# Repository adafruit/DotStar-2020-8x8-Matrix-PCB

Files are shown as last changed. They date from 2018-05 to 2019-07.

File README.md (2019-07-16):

## Adafruit DotStar High Density 8x8 Grid - 64 RGB LED Pixel Matrix PCB

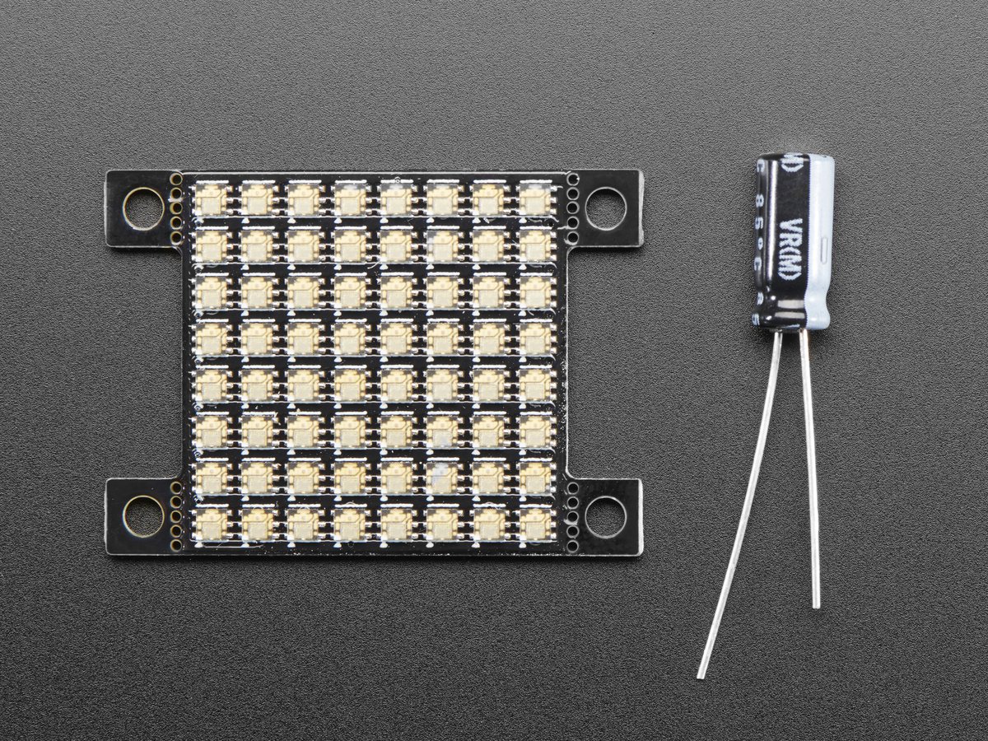
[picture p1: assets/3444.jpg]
<a href="http://www.adafruit.com/products/3444"><br/>
Click here to purchase one from the Adafruit shop</a>

PCB files for the Adafruit DotStar High Density 8x8 Grid - 64 RGB LED Pixel Matrix. Format is EagleCAD schematic and board layout
* https://www.adafruit.com/product/3444

### Description

Do not eat this LED grid just because it is so colorful and bite-sized! This is the tiniest little LED grid we could make, with 64 full RGB color pixels in a square that is only 1" by 1" square (thats 25.4mm x 25.4mm for you metric-lovers). Best of all, these are little DotStar LEDs, with built in PWM drivers, so you only need two digital I/O pins to get a-glowin'.

But do not be fooled by their small size, each LED is still incredibly, blindingly bright just like the DotStars/NeoPixels you know and love. These are the same integrated LEDs that are used in [our new fancy DotStar strips](https://www.adafruit.com/categories/885) just really small.

Arranged in an 8x8 matrix, each pixel is individually addressable: like NeoPixels, DotStar LEDs have an embedded microcontroller **inside the LED**. You can set the color/brightness of each LED to 24-bit color (8 bits each red green and blue). Each LED acts like a shift register, reading incoming color data on the input pins, and then shifting the previous color data out on the output pin. By sending a long string of data, you can control an 'infinite' number of LEDs. The PWM is built into each LED-chip so once you set the color you can stop talking to the disk and it will continue to PWM all the LEDs for you.

Wiring it up is easy: there are two 4-pad connection ports on the back. Solder wires to the input port (+5V GND ClockIn and DataIn) and provide 5VDC to the +5V and ground pins, then connect the CIN/DIN pin to your microcontroller. If you have hardware SPI, use the SCK and MOSI pins respectively. You'll also need to make a common ground from the 5V power supply to the microcontroller/Arduino. Since each LED can draw as much as 40mA (thats up to 2.5 Amps per panel if all LEDs are on bright white!) we suggest our 5V 2A power supply if you're going to use full brightness and a lot of white. For most uses, you'll see about 0.5A of current per panel, and you can set the brightness to drop that down. Note that so much current through a small board can make it toasty!

To keep the board small, we did not put any small surface-mount capacitors on the front. Instead, there's a power/ground pad set on the back and a 220uF capacitor that you can solder onto the back for a compact fit. There's also four mounting holes that you can use for attachment, or snap them off with pliers if you want a perfect 1" square.

[Check out our tutorial showing wiring, power usage calculations, example code for usage, etc!](https://learn.adafruit.com/adafruit-dotstar-leds)

### License

Adafruit invests time and resources providing this open source design, please support Adafruit and open-source hardware by purchasing products from [Adafruit](https://www.adafruit.com)!

Designed by Limor Fried/Ladyada for Adafruit Industries.

Creative Commons Attribution/Share-Alike, all text above must be included in any redistribution. See license.txt for additional details.

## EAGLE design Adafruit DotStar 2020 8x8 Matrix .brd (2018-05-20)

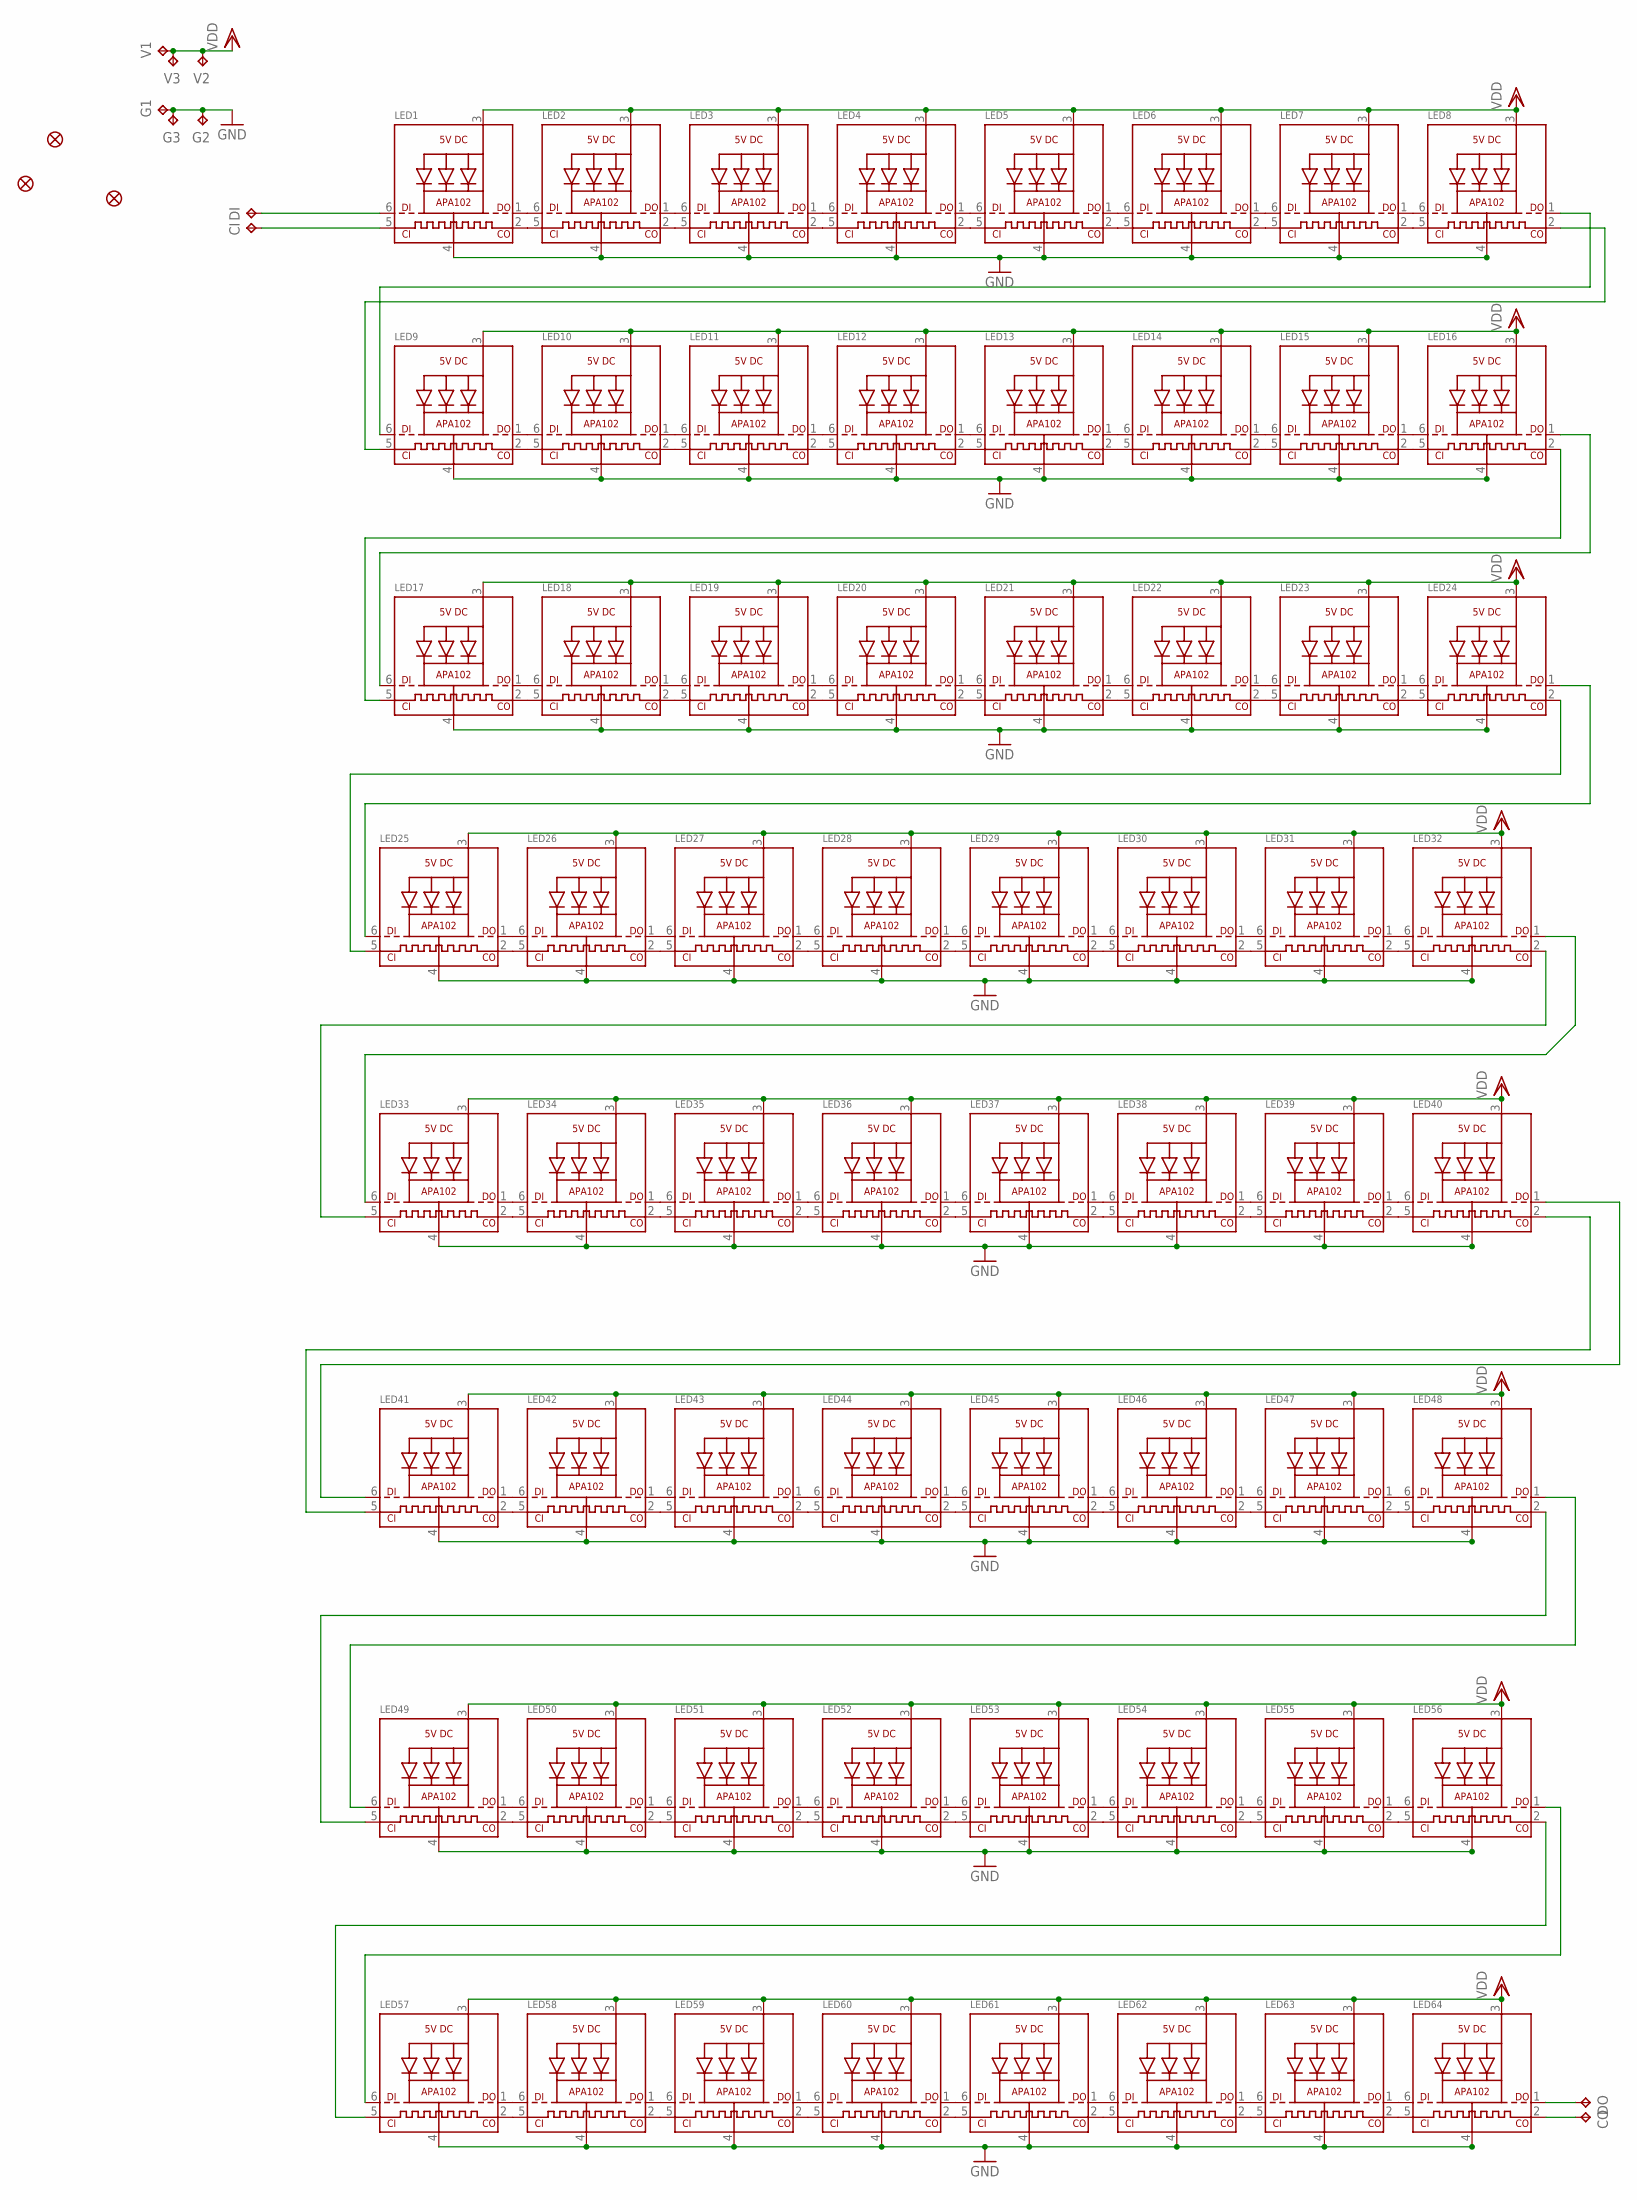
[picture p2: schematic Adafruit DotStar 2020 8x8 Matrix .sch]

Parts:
CI: TPTP20R; TP20R
CO: TPTP20R; TP20R
DI: TPTP20R; TP20R
DO: TPTP20R; TP20R
FID1, FID2, FID3: FIDUCIAL_0.5MM
G1, G2, G3: TPTP20R; TP20R
LED1, LED2, LED3, LED4, LED5, LED6, LED7, LED8, LED9, LED10, LED11, LED12, LED13, LED14, LED15, LED16, LED17, LED18, LED19, LED20, LED21, LED22, LED23, LED24, LED25, LED26, LED27, LED28, LED29, LED30, LED31, LED32, LED33, LED34, LED35, LED36, LED37, LED38, LED39, LED40, LED41, LED42, LED43, LED44, LED45, LED46, LED47, LED48, LED49, LED50, LED51, LED52, LED53, LED54, LED55, LED56, LED57, LED58, LED59, LED60, LED61, LED62, LED63, LED64: APA1022020; APA102_2020
V1, V2, V3: TPTP20R; TP20R

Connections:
C0: CO.TP, LED64.2 (CKO)
CIN: CI.TP, LED1.5 (CKI)
D0: DO.TP, LED64.1 (DO)
DIN: DI.TP, LED1.6 (DI)
GND: G1.TP, G2.TP, G3.TP, LED1.4 (GND), LED2.4 (GND), LED3.4 (GND), LED4.4 (GND), LED5.4 (GND), LED6.4 (GND), LED7.4 (GND), LED8.4 (GND), LED9.4 (GND), LED10.4 (GND), LED11.4 (GND), LED12.4 (GND), LED13.4 (GND), LED14.4 (GND), LED15.4 (GND), LED16.4 (GND), LED17.4 (GND), LED18.4 (GND), LED19.4 (GND), LED20.4 (GND), LED21.4 (GND), LED22.4 (GND), LED23.4 (GND), LED24.4 (GND), LED25.4 (GND), LED26.4 (GND), LED27.4 (GND), LED28.4 (GND), LED29.4 (GND), LED30.4 (GND), LED31.4 (GND), LED32.4 (GND), LED33.4 (GND), LED34.4 (GND), LED35.4 (GND), LED36.4 (GND), LED37.4 (GND), LED38.4 (GND), LED39.4 (GND), LED40.4 (GND), LED41.4 (GND), LED42.4 (GND), LED43.4 (GND), LED44.4 (GND), LED45.4 (GND), LED46.4 (GND), LED47.4 (GND), LED48.4 (GND), LED49.4 (GND), LED50.4 (GND), LED51.4 (GND), LED52.4 (GND), LED53.4 (GND), LED54.4 (GND), LED55.4 (GND), LED56.4 (GND), LED57.4 (GND), LED58.4 (GND), LED59.4 (GND), LED60.4 (GND), LED61.4 (GND), LED62.4 (GND), LED63.4 (GND), LED64.4 (GND)
unnamed: LED1.1 (DO), LED2.6 (DI)
unnamed: LED1.2 (CKO), LED2.5 (CKI)
unnamed: LED2.1 (DO), LED3.6 (DI)
unnamed: LED2.2 (CKO), LED3.5 (CKI)
unnamed: LED3.1 (DO), LED4.6 (DI)
unnamed: LED3.2 (CKO), LED4.5 (CKI)
unnamed: LED4.1 (DO), LED5.6 (DI)
unnamed: LED4.2 (CKO), LED5.5 (CKI)
unnamed: LED5.1 (DO), LED6.6 (DI)
unnamed: LED5.2 (CKO), LED6.5 (CKI)
unnamed: LED6.1 (DO), LED7.6 (DI)
unnamed: LED6.2 (CKO), LED7.5 (CKI)
unnamed: LED7.1 (DO), LED8.6 (DI)
unnamed: LED7.2 (CKO), LED8.5 (CKI)
unnamed: LED9.1 (DO), LED10.6 (DI)
unnamed: LED9.2 (CKO), LED10.5 (CKI)
unnamed: LED10.1 (DO), LED11.6 (DI)
unnamed: LED10.2 (CKO), LED11.5 (CKI)
unnamed: LED11.1 (DO), LED12.6 (DI)
unnamed: LED11.2 (CKO), LED12.5 (CKI)
unnamed: LED12.1 (DO), LED13.6 (DI)
unnamed: LED12.2 (CKO), LED13.5 (CKI)
unnamed: LED13.1 (DO), LED14.6 (DI)
unnamed: LED13.2 (CKO), LED14.5 (CKI)
unnamed: LED14.1 (DO), LED15.6 (DI)
unnamed: LED14.2 (CKO), LED15.5 (CKI)
unnamed: LED15.1 (DO), LED16.6 (DI)
unnamed: LED15.2 (CKO), LED16.5 (CKI)
unnamed: LED17.1 (DO), LED18.6 (DI)
unnamed: LED17.2 (CKO), LED18.5 (CKI)
unnamed: LED18.1 (DO), LED19.6 (DI)
unnamed: LED18.2 (CKO), LED19.5 (CKI)
unnamed: LED19.1 (DO), LED20.6 (DI)
unnamed: LED19.2 (CKO), LED20.5 (CKI)
unnamed: LED20.1 (DO), LED21.6 (DI)
unnamed: LED20.2 (CKO), LED21.5 (CKI)
unnamed: LED21.1 (DO), LED22.6 (DI)
unnamed: LED21.2 (CKO), LED22.5 (CKI)
unnamed: LED22.1 (DO), LED23.6 (DI)
unnamed: LED22.2 (CKO), LED23.5 (CKI)
unnamed: LED23.1 (DO), LED24.6 (DI)
unnamed: LED23.2 (CKO), LED24.5 (CKI)
unnamed: LED25.1 (DO), LED26.6 (DI)
unnamed: LED25.2 (CKO), LED26.5 (CKI)
unnamed: LED26.1 (DO), LED27.6 (DI)
unnamed: LED26.2 (CKO), LED27.5 (CKI)
unnamed: LED27.1 (DO), LED28.6 (DI)
unnamed: LED27.2 (CKO), LED28.5 (CKI)
unnamed: LED28.1 (DO), LED29.6 (DI)
unnamed: LED28.2 (CKO), LED29.5 (CKI)
unnamed: LED29.1 (DO), LED30.6 (DI)
unnamed: LED29.2 (CKO), LED30.5 (CKI)
unnamed: LED30.1 (DO), LED31.6 (DI)
unnamed: LED30.2 (CKO), LED31.5 (CKI)
unnamed: LED31.1 (DO), LED32.6 (DI)
unnamed: LED31.2 (CKO), LED32.5 (CKI)
unnamed: LED33.1 (DO), LED34.6 (DI)
unnamed: LED33.2 (CKO), LED34.5 (CKI)
unnamed: LED34.1 (DO), LED35.6 (DI)
unnamed: LED34.2 (CKO), LED35.5 (CKI)
unnamed: LED35.1 (DO), LED36.6 (DI)
unnamed: LED35.2 (CKO), LED36.5 (CKI)
unnamed: LED36.1 (DO), LED37.6 (DI)
unnamed: LED36.2 (CKO), LED37.5 (CKI)
unnamed: LED37.1 (DO), LED38.6 (DI)
unnamed: LED37.2 (CKO), LED38.5 (CKI)
unnamed: LED38.1 (DO), LED39.6 (DI)
unnamed: LED38.2 (CKO), LED39.5 (CKI)
unnamed: LED39.1 (DO), LED40.6 (DI)
unnamed: LED39.2 (CKO), LED40.5 (CKI)
unnamed: LED41.1 (DO), LED42.6 (DI)
unnamed: LED41.2 (CKO), LED42.5 (CKI)
unnamed: LED42.1 (DO), LED43.6 (DI)
unnamed: LED42.2 (CKO), LED43.5 (CKI)
unnamed: LED43.1 (DO), LED44.6 (DI)
unnamed: LED43.2 (CKO), LED44.5 (CKI)
unnamed: LED44.1 (DO), LED45.6 (DI)
unnamed: LED44.2 (CKO), LED45.5 (CKI)
unnamed: LED45.1 (DO), LED46.6 (DI)
unnamed: LED45.2 (CKO), LED46.5 (CKI)
unnamed: LED46.1 (DO), LED47.6 (DI)
unnamed: LED46.2 (CKO), LED47.5 (CKI)
unnamed: LED47.1 (DO), LED48.6 (DI)
unnamed: LED47.2 (CKO), LED48.5 (CKI)
unnamed: LED49.1 (DO), LED50.6 (DI)
unnamed: LED49.2 (CKO), LED50.5 (CKI)
unnamed: LED50.1 (DO), LED51.6 (DI)
unnamed: LED50.2 (CKO), LED51.5 (CKI)
unnamed: LED51.1 (DO), LED52.6 (DI)
unnamed: LED51.2 (CKO), LED52.5 (CKI)
unnamed: LED52.1 (DO), LED53.6 (DI)
unnamed: LED52.2 (CKO), LED53.5 (CKI)
unnamed: LED53.1 (DO), LED54.6 (DI)
unnamed: LED53.2 (CKO), LED54.5 (CKI)
unnamed: LED54.1 (DO), LED55.6 (DI)
unnamed: LED54.2 (CKO), LED55.5 (CKI)
unnamed: LED55.1 (DO), LED56.6 (DI)
unnamed: LED55.2 (CKO), LED56.5 (CKI)
unnamed: LED57.1 (DO), LED58.6 (DI)
unnamed: LED57.2 (CKO), LED58.5 (CKI)
unnamed: LED58.1 (DO), LED59.6 (DI)
unnamed: LED58.2 (CKO), LED59.5 (CKI)
unnamed: LED59.1 (DO), LED60.6 (DI)
unnamed: LED59.2 (CKO), LED60.5 (CKI)
unnamed: LED60.1 (DO), LED61.6 (DI)
unnamed: LED60.2 (CKO), LED61.5 (CKI)
unnamed: LED61.1 (DO), LED62.6 (DI)
unnamed: LED61.2 (CKO), LED62.5 (CKI)
unnamed: LED62.1 (DO), LED63.6 (DI)
unnamed: LED62.2 (CKO), LED63.5 (CKI)
unnamed: LED63.1 (DO), LED64.6 (DI)
unnamed: LED63.2 (CKO), LED64.5 (CKI)
unnamed: LED8.1 (DO), LED9.6 (DI)
unnamed: LED8.2 (CKO), LED9.5 (CKI)
unnamed: LED16.1 (DO), LED17.6 (DI)
unnamed: LED16.2 (CKO), LED17.5 (CKI)
unnamed: LED24.1 (DO), LED25.6 (DI)
unnamed: LED24.2 (CKO), LED25.5 (CKI)
unnamed: LED32.1 (DO), LED33.6 (DI)
unnamed: LED32.2 (CKO), LED33.5 (CKI)
unnamed: LED56.1 (DO), LED57.6 (DI)
unnamed: LED56.2 (CKO), LED57.5 (CKI)
unnamed: LED48.2 (CKO), LED49.5 (CKI)
unnamed: LED48.1 (DO), LED49.6 (DI)
unnamed: LED40.2 (CKO), LED41.5 (CKI)
unnamed: LED40.1 (DO), LED41.6 (DI)
VDD: LED1.3 (VDD), LED2.3 (VDD), LED3.3 (VDD), LED4.3 (VDD), LED5.3 (VDD), LED6.3 (VDD), LED7.3 (VDD), LED8.3 (VDD), LED9.3 (VDD), LED10.3 (VDD), LED11.3 (VDD), LED12.3 (VDD), LED13.3 (VDD), LED14.3 (VDD), LED15.3 (VDD), LED16.3 (VDD), LED17.3 (VDD), LED18.3 (VDD), LED19.3 (VDD), LED20.3 (VDD), LED21.3 (VDD), LED22.3 (VDD), LED23.3 (VDD), LED24.3 (VDD), LED25.3 (VDD), LED26.3 (VDD), LED27.3 (VDD), LED28.3 (VDD), LED29.3 (VDD), LED30.3 (VDD), LED31.3 (VDD), LED32.3 (VDD), LED33.3 (VDD), LED34.3 (VDD), LED35.3 (VDD), LED36.3 (VDD), LED37.3 (VDD), LED38.3 (VDD), LED39.3 (VDD), LED40.3 (VDD), LED41.3 (VDD), LED42.3 (VDD), LED43.3 (VDD), LED44.3 (VDD), LED45.3 (VDD), LED46.3 (VDD), LED47.3 (VDD), LED48.3 (VDD), LED49.3 (VDD), LED50.3 (VDD), LED51.3 (VDD), LED52.3 (VDD), LED53.3 (VDD), LED54.3 (VDD), LED55.3 (VDD), LED56.3 (VDD), LED57.3 (VDD), LED58.3 (VDD), LED59.3 (VDD), LED60.3 (VDD), LED61.3 (VDD), LED62.3 (VDD), LED63.3 (VDD), LED64.3 (VDD), V1.TP, V2.TP, V3.TP

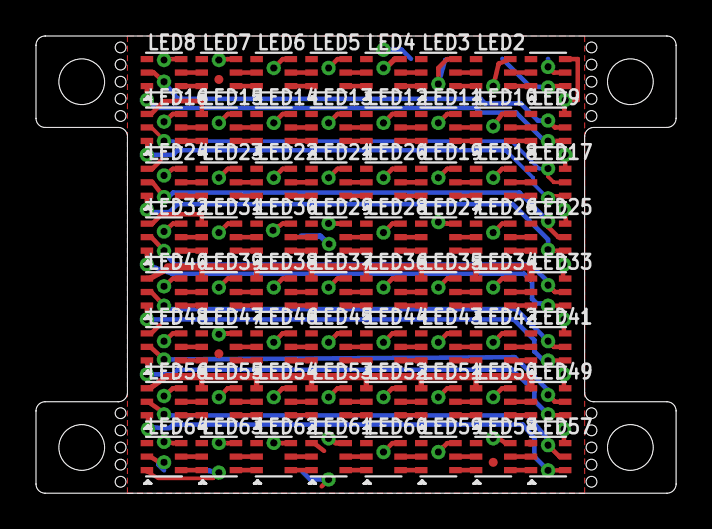
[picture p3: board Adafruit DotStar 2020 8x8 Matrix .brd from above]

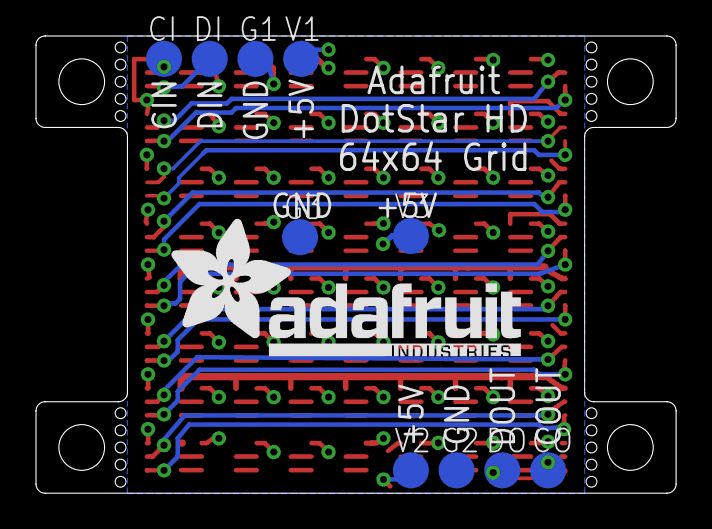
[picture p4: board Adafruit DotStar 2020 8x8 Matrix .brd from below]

Board: 2 copper layers, 35.6 x 25.4 mm, 78 parts (11 on the bottom side), 132 nets.

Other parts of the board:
U$1: ADAFRUIT_TEXT_20MM

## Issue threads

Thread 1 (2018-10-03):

6 pads per LED, or 8?

R-OLE, 2018-10-03:
Your datasheet on Adafruit's [LED Dotstar 2020 product page](https://www.adafruit.com/product/3341) links to an (older? wrong, since the color profile product change?) datasheet that shows on its front page a picture of the bottom of the package with two pads on the centerline of the chip.
The same datasheet then does NOT show those two pads in the physical dimensions section on page two, but rather a odd sideways "hat" shaped pad, without any dimensions.
And again on your [product page](https://www.adafruit.com/product/3341), the bottom of the LED is shown, viewed sitting on a US quarter, and it clearly shows there are two central pads.

**Q**: Is this a current datasheet for the Dotstar 2020's parts you're selling?
**Q**: Is this a current datasheet for the Dotstar 2020's you're using on boards?
**Q**: Are there actually not any pads here on some version of these LEDs you used to build these boards?

Which brings us to the design - the 2020 LED footprint you used here have potential issues from ignoring these two pads if folks are trying to re-use your design...

I say potential issues, because if Vdd and GND are exposed by these pads on the underside of these LEDs, it could create real world clearance problems from other components (added decoupling caps?) with pads near an LED's centerline, or even short circuits if copper is exposed if there are vias under the centerline of the LED, if said vias are not tented over with soldermask like you have on your board (even then it is not foolproof - soldermasks can have holes from the bare board fabricator or be damaged during handling and/or assembly).

I recognize this was a tight design, probably aimed at getting these LEDs as close as possible, while keeping it as cost effective as possible (nicely done, BTW). And one way to do that would be to make sure this layout has no exposed vias or other copper under the LEDs or near their centerline's edge to cause problems with these central pads.
It is a bit of sleight of hand to do that, and can surely be considered acceptable when the issues are **clearly stated** and understood. Not so nice when it is a hidden "feature".

Off the top of my head, I'd say this tradeoff has the following detractions, to be traded off against increased component density:
- reduces the power dissipation path available to the LEDs (LEDs run hotter, or should be run as long or brightly),
- reduces the power delivery "copper width" to the LED (increases chances of starving the LED and/or resetting the controller die inside)(not so much with your surface flooded power and ground planes),
- raises potential gotcha's for unsuspecting souls following in your footsteps, as I outlined above.

It is nice when there is a text file to share some notes and guidelines, just as many designers include in their zipped up files to be sent off for build. Of course the Readme.md file could provide this same function...

Aside and regardless of the above, **thank you** very much for sharing this design with the world.

ladyada, 2018-10-03:
hiya, we just dont connect the mysterious center pads. if you make the PCB as uploaded with solder mask and no via exposure, then we've had no problems. we'll add a note to the readme.

ladyada, 2018-10-03:
we have no other datasheet than what is on the product page. these LEDs are poorly documented!

ladyada, 2018-10-03:
if you have other manufacturing insights you'd like to add please submit a PR for the readme or other documents! :)

Closed 2018-10-03.

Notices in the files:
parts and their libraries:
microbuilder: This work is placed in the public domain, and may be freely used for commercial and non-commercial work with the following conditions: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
